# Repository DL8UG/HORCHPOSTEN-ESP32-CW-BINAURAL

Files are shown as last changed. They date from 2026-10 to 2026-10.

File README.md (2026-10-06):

# Horchposten – ESP32 CW Binaural

Binaural CW headphone processor for the ESP32-Audio-Kit (ESP32-A1S).
The audio of a CW transceiver goes into the LINE IN jack; Horchposten
spreads the signals over the stereo image of your headphones, so stations
at different pitches appear at different places and the wanted signal
stands out of the noise.

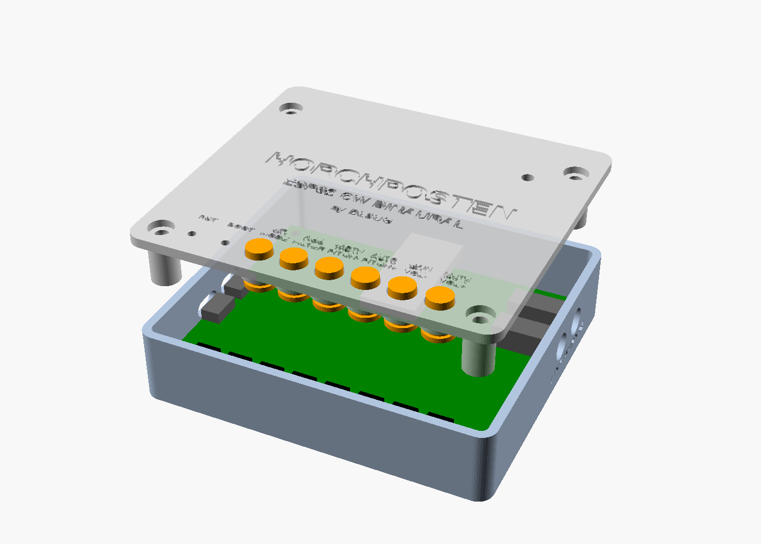
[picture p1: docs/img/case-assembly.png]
Enclosure


> **Status:** work in progress. Signal chain tested on the PC
> (host tests), firmware builds; not yet tested on the hardware.

## Contents

- [Features](#features)
- [Hardware](#hardware)
- [Wiring](#wiring)
- [Keys](#keys)
- [Modes](#modes)
  - [Binaural by pitch](#binaural-by-pitch)
  - [Binaural 90 degrees](#binaural-90-degrees)
  - [Haas](#haas)
  - [Mono](#mono)
- [Filter, AGC and auto pitch](#filter-agc-and-auto-pitch)
- [Flashing](#flashing)
- [Building from source](#building-from-source)
- [Enclosure](#enclosure)
- [Feedback](#feedback)
- [License](#license)
- [Credits](#credits)

## Features

- Four listening modes: binaural by pitch, binaural 90°, Haas, mono
- CW band pass around the centre pitch: off / 500 / 250 / 100 Hz
  (Butterworth, 8th order)
- AGC for strong and weak signals, soft limiter protects the ears
- Auto pitch: one key press sets the centre pitch to the strongest tone
- All settings on six keys, kept over power off
- Codec detection: ES8388 (Audio Kit V2.2) and AC101 boards
- 3D printable enclosure (OpenSCAD, parametric)

## Hardware

- ESP32-Audio-Kit with the ESP32-A1S module (AI-Thinker), V2.2 with
  ES8388 codec; the older AC101 variant is supported but untested
- Headphones (stereo, of course)
- Cable from the transceiver's headphone or line output to the LINE IN jack
- Power over the micro USB socket "POWER" (or "UART", which is also used
  for flashing)

The speaker outputs of the board stay off.

ESP32-Audio-Kit V2.2 from above: keys RST, BOOT, KEY1 to KEY6 along the front edge, EARPHONES and LINE IN on the right, micro USB on the left, DIP switch in the middle, the two microphones marked for removal

**Remove the on-board microphones.** They share the codec input with the
LINE IN jack, and a plug in the jack does not cut them off: on a V2.2
board marked A618, tapping a microphone reached −8 dBFS, louder than a
line signal from a PC, and speech in the room came through. Desolder
both, or cut one leg of each (the one not on the ground plane); then a
tap stays below −45 dBFS. Don't bridge their legs instead: that may
short the line input to ground as well.

## Wiring

Input and output are ordinary 3.5 mm jacks. That keeps Horchposten
universal: it can be put into any headphone connection, between the
transceiver and the headphones (a 6.3 mm socket or plug needs only the
usual adapter).

```
Transceiver            ESP32-Audio-Kit
phones / line out ---> LINE IN  (3.5 mm, tip = left channel is used)
                       PHONES   ---> headphones
                       USB      ---> 5 V
```

- A mono plug works: only the tip (left channel) is used.
- Start with the transceiver's volume low and raise it until the AGC
  holds the level; with AGC off, raise the input gain (KEY5 long) instead.
- If the transceiver has a fixed line output (ACC, data port), use it:
  then the transceiver's volume knob doesn't matter.

## Keys

| Key | Short press | Long press (0.6 s) |
|---|---|---|
| KEY1 | mode: pitch → 90° → Haas → mono | swap left / right |
| KEY2 | filter: off → 500 → 250 → 100 Hz | AGC on / off |
| KEY3 | centre pitch −25 Hz | stereo width: narrow → medium → wide |
| KEY4 | centre pitch +25 Hz | auto pitch |
| KEY5 | volume − | input gain: 0 → 6 → … → 24 dB |
| KEY6 | volume + | mute on / off |

The green LED confirms with short blinks (e.g. the number of the new mode);
one long blink means "not possible" (end of a range, auto pitch found no
clear tone). Every change is also printed in the serial log. Settings are
saved 3 s after the last change; the audio fades out for about 50
milliseconds while the flash is written. Mute is not kept, Horchposten
always starts unmuted.

Centre pitch range: 300–1000 Hz, default 600 Hz. Tip: set it to the CW
pitch of your transceiver, then your own sidetone and a station zero-beat
by the transceiver are in the middle.

KEY2 shares GPIO13 with the SD card and JTAG. If it doesn't react, check
the DIP switch next to the SD slot.

## Modes

How every stage works, with the formulas and numbers behind it, is
explained in [docs/algorithms.md](docs/algorithms.md).

### Binaural by pitch

The main mode. A signal exactly on the centre pitch is in the middle of
your head; lower tones move to the left, higher ones to the right. Several
stations in the passband are spread over the stereo image instead of
lying on top of each other.

How: the signal is split into I and Q (90° apart, Hilbert transformer);
one ear gets the signal, the other the same signal delayed by D and
turned back by the phase of the centre pitch. The phase between the ears
is then 2π (f − f<sub>centre</sub>) D: zero on the centre pitch, growing
with the distance from it. This follows the idea of Rick Campbell's (KK7B)
binaural I/Q receivers, but keeps the pitch of each tone.
The width (KEY3 long) sets D: 90° between the ears is reached 500 Hz
(narrow), 310 Hz (medium) or 200 Hz (wide) away from the centre pitch.

### Binaural 90 degrees

Left and right ear are 90° apart at every frequency. Noise sounds wide and
diffuse, a CW signal stays focussed and seems to stand in front of the
noise.

### Haas

One ear gets the signal some milliseconds later (8 / 15 / 25 ms, by
width). A broad, spacious sound.

### Mono

Both ears the same, for comparison.

## Filter, AGC and auto pitch

- **Filter** (KEY2): band pass centred on the centre pitch. It follows
  every change of the pitch.
- **AGC** (KEY2 long): 3 ms look-ahead, so the first element after a
  pause is no louder than the rest; 150 ms hang, slow decay. Keeps the
  level between weak and strong signals over up to about 35 dB.
- **Auto pitch** (KEY4 long): listens for 0.3 s and sets the centre pitch
  to the strongest tone between 300 and 1000 Hz, if it stands at least
  14 dB above the noise 20–60 Hz beside it. This also works behind a
  narrow CW filter in the transceiver.

## Flashing

Each [release](https://github.com/DL8UG/HORCHPOSTEN-ESP32-CW-BINAURAL/releases) has `horchposten-vX.Y.Z-merged.bin`, one
image for address 0x0:

```sh
pip install esptool
esptool.py --chip esp32 --port /dev/ttyUSB0 write_flash 0x0 horchposten-vX.Y.Z-merged.bin
```

Use the micro USB socket "UART". If the board doesn't enter the download
mode by itself, hold BOOT and press RST. The browser tool
[ESP Tool](https://espressif.github.io/esptool-js/) works too.

## Building from source

ESP-IDF v5.5:

```sh
cd firmware
idf.py set-target esp32
idf.py build flash monitor
```

`idf.py menuconfig` → "Horchposten": codec (auto / fixed), input channel,
LED polarity.

The signal chain (`firmware/main/dsp.c`, `pitch.c`) is plain C and is
tested on the PC:

```sh
make -C firmware/test/host       # checks
make -C firmware/test/host wav   # plus WAV files to listen to (build/wav/, emptied first)
```

The WAV files (16 kHz stereo, listen with headphones) show each part of
the signal chain. The input files are brought to the level of the
processed ones, so loudness doesn't decide the comparison:

| Files | What to listen for |
|---|---|
| `01`–`05` pile-up | three CW stations (480, 600, 760 Hz) in noise: the input, then mono, pitch, 90° and Haas |
| `06`–`07` width | pitch mode narrow / wide on the same pile-up (medium is the default: `03`) |
| `08`–`10` filter | pitch mode with 500 / 250 / 100 Hz |
| `11` sweep | one tone gliding from 300 to 1000 Hz: travels from left to right, in the middle at 600 Hz |
| `12`–`14` AGC | weak station, a very strong one, weak again: the input, AGC on, AGC off |
| `15` changes | a setting changed every 1.5 s on the pile-up (list in `15_changes.txt`); the checks run the same changes on a clean tone and fail on any click |

## Enclosure

A parametric 3D printable enclosure is in [case/](case/README.md). It is
a **draft**: not printed or tested yet, but a solid base for your own
design. Measure your board before printing; the README there says what to
measure.

## Feedback

Please open a [GitHub issue](https://github.com/DL8UG/HORCHPOSTEN-ESP32-CW-BINAURAL/issues) – with the firmware version and
codec from the serial log, your transceiver, and what you did.

## License

Beerware, see [LICENSE](LICENSE).

## Credits

- Binaural I/Q reception: Rick Campbell, KK7B
- Hilbert transformer (allpass pair): Olli Niemitalo
- Board and codec details: the arduino-audiokit project by Phil Schatzmann
  and the Linux AC101 driver (respeaker/seeed-voicecard)

Developed with the help of Claude Code.

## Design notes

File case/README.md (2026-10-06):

# Enclosure

Parametric enclosure for the ESP32-Audio-Kit V2.2 in OpenSCAD:
[horchposten_case.scad](horchposten_case.scad).

Enclosure, exploded view

> **Draft:** this enclosure has not been printed or tested yet. Take it as
> a solid base for your own design.
>
> The layout (one row of eight keys in front, jacks on the right, USB on
> the left, the module antenna out over the back edge) is checked on a
> V2.2 board marked A618. The millimetres come from a product photo with
> dimensions and are **estimates**: measure your board and correct the
> values before the first print (see [Measuring](#measuring)).

## Contents

- [Parts](#parts)
- [Measuring](#measuring)
- [Building the STL files](#building-the-stl-files)
- [Printing](#printing)
- [Assembly](#assembly)
- [Display window](#display-window)

## Parts

| Part | Count | Notes |
|---|---|---|
| `bottom` | 1 | shell with standoffs, openings for the jacks and USB, vent slots |
| `lid` | 1 | key guides, lettering, holes for RESET/BOOT and the LED |
| `buttons` | 1 set | six key plungers |
| M3 x 16 button head screws (ISO 7380) | 4 | through lid and PCB into the standoffs; cap screws (DIN 912) are too tall for the counterbore |
| M3 heat-set inserts | 4 | 4.0 mm hole; for self-tapping screws set `insert_d = 2.6` |
| rubber feet | 4 | 10 mm, self-adhesive |
| clear filament, 3 mm long | 1 | light pipe for the status LED (optional) |

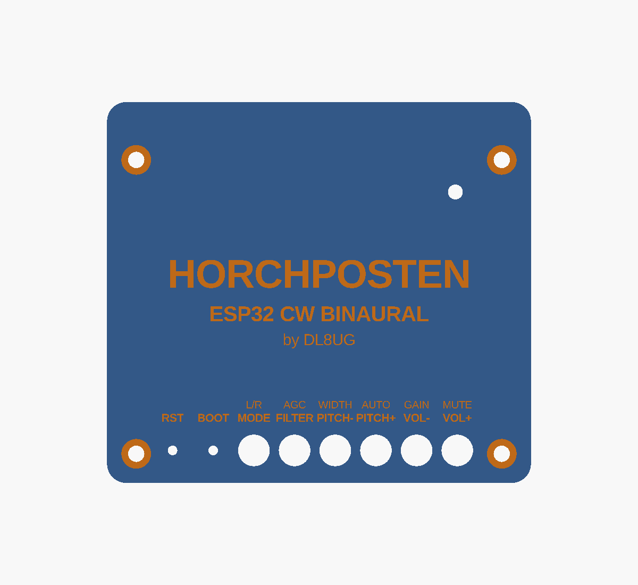
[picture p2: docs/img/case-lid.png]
Lid


## Measuring

All values are in the block "board (MEASURE)" at the top of the SCAD file.
Coordinates are in mm, seen from the top of the board, origin at the front
left corner of the PCB, front edge = the side with the row of keys (from
the left: RST, BOOT, KEY1..KEY6).

| Parameter | What to measure |
|---|---|
| `pcb`, `pcb_t` | PCB size and thickness |
| `holes`, `hole_d` | centres of the four mounting holes |
| `under_h` | tallest part on the underside (solder pins) + 1 mm |
| `over_h` | tallest part on the top + 1 mm |
| `antenna` | x range of the module end that sticks out over the back edge, and how far it sticks out |
| `key_row`, `key_pitch`, `key_top` | centre of RST; distance from key to key; height of the key actuator above the PCB. KEY1..KEY6 and the holes for RST and BOOT follow from these |
| `led` | centre of the status LED (GPIO22) |
| `ports` | for both 3.5 mm jacks (right side) and both micro USB sockets (left side): side, position along that side, centre height above the PCB, opening size |

Check after editing: `part = "assembly"` shows the board dummy in the
shell; jacks and USB plugs must line up with the openings.

## Building the STL files

Ready STL files are in [stl/](stl/), rendered from the SCAD file with the
estimated board positions. After changing parameters, render them again:

```sh
for p in bottom lid buttons; do
  openscad -o stl/$p.stl -D "part=\"$p\"" horchposten_case.scad
done
```

The release workflow does the same and attaches a zip with the STL files
and the SCAD source to each GitHub release.

## Printing

- PLA or PETG, 0.2 mm layers, 3 walls, 20 % infill, no supports.
- `bottom` stands on its floor, `lid` comes out upside down (top face on
  the bed, the lettering is engraved into it), `buttons` stand on their
  flanges.
- Print `buttons` in a different colour from the lid (they are a separate
  part anyway), so the six keys stand out; e.g. a light grey lid with
  orange keys, as in the pictures.
- Contrasting lettering: rub acrylic paint into the engraving and wipe
  the surface clean.

## Assembly

1. Press the heat-set inserts into the standoffs.
2. Put the board in, jacks first through the side openings.
3. Stand the plungers on the keys, flange down, and lower the lid over
   them so that each slides into its guide. (Dropped into the lid from
   below, they fall out when it is turned over; if they won't stand,
   hold them in the lid with a strip of tape across its top face and
   pull it off at the end.) Fasten the lid with the four screws. Don't
   overtighten: the lid tubes clamp the PCB. They are `tube_press`
   (0.2 mm) longer than the room above the board; if a gap stays at the
   rim, lower that value.
4. Rubber feet into the recesses under the bottom.

## Display window

For the later display stage set `display_window = true` and give the
position and size of the window (`display_pos`, `display_size`). If the
display needs more height, raise `over_h`.

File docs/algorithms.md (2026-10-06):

# How Horchposten works

This document explains the signal chain and the auto pitch in detail: what
each stage does, why it is built that way, and the numbers it uses. The
code is in [firmware/main/dsp.c](../firmware/main/dsp.c),
[firmware/main/pitch.c](../firmware/main/pitch.c) and
[firmware/main/audio_io.c](../firmware/main/audio_io.c); the host tests in
[firmware/test/host](../firmware/test/host/dsp_test.c) check the claims made
here.

## Contents

- [Overview](#overview)
- [Audio path and clocks](#audio-path-and-clocks)
- [DC block](#dc-block)
- [CW band pass](#cw-band-pass)
- [AGC](#agc)
- [Hilbert pair: I and Q](#hilbert-pair-i-and-q)
- [Stereo modes](#stereo-modes)
  - [Binaural by pitch](#binaural-by-pitch)
  - [Binaural 90 degrees](#binaural-90-degrees)
  - [Haas](#haas)
  - [Mono and swap](#mono-and-swap)
- [Soft limiter](#soft-limiter)
- [Changes without clicks](#changes-without-clicks)
  - [Handing over new settings](#handing-over-new-settings)
  - [Mode, width and swap](#mode-width-and-swap)
  - [Centre pitch](#centre-pitch)
  - [Band pass](#band-pass)
  - [AGC on and off](#agc-on-and-off)
  - [Output fader and volume](#output-fader-and-volume)
- [Auto pitch](#auto-pitch)
- [How it is tested](#how-it-is-tested)

## Overview

```
LINE IN ─► ADC ─► DC block ─► band pass ─► AGC ─► Hilbert pair ─┬─ I ─► stereo stage ─► limiter ─► fader ─► DAC ─► headphones
 (left)    16 kHz  20 Hz      off/500/     35 dB   90° apart    └─ Q ─►  (mode, width,
                              250/100 Hz                                  swap)
```

Everything runs on one mono input (the left channel of LINE IN) at
16 kHz, in blocks of 64 samples (4 ms). The stereo stage is the only part
that makes two channels. Every change of a setting is faded, so nothing
clicks.

## Audio path and clocks

The ESP32 is I2S master: it sends the bit clock (BCK, 32 × fs), the word
clock (WS, fs) and the codec's master clock (MCLK, 256 × fs) on GPIO0.
The codec (ES8388 on the Audio Kit V2.2) is slave, 16 bit Philips format.

MCLK comes from the ESP32's default PLL, **not from the APLL**. With MCLK
from the APLL, the ES8388 DAC hissed loudly whenever it got any non-zero
data, louder than a tone at −20 dBFS; with the default PLL the output is
clean (found on the board, see the commit history).

The audio task runs on core 1 at high priority: read a block from the
ADC, process it, write it to the DAC. Four DMA buffers of one block each
give 16 ms of buffering.

## DC block

A one-pole high pass removes any DC offset of the ADC before the filters:

```
y[n] = x[n] − x[n−1] + 0.992 · y[n−1]
```

The corner is at (1 − 0.992) · fs / 2π ≈ 20 Hz, far below any CW pitch.

## CW band pass

Four settings: off, 500, 250 and 100 Hz wide, centred on the centre
pitch (300…1000 Hz).

**Design.** A Butterworth band pass of order 8, built from 4 second order
sections (biquads), designed in the firmware when a setting changes:

1. Low pass prototype of order 4: poles on the left half of the unit
   circle, `p_k = e^{jπ(2k + 5)/8}`.
2. Low pass to band pass transform with the band edges pre-warped for the
   bilinear transform: `ω_l = 2fs·tan(π f_l / fs)`, `ω_h` likewise,
   `B = ω_h − ω_l`, `ω0² = ω_l·ω_h`. Each prototype pole gives two band
   pass poles, roots of `s² − p·B·s + ω0² = 0`.
3. Bilinear transform `z = (2fs + s) / (2fs − s)`; only the poles with a
   positive imaginary part are kept, their conjugates are implied.
4. Each section has its zeros at z = 1 and z = −1 (numerator 1 − z⁻²) and
   is scaled to 0 dB at the centre.

The result is −3 dB at fc ± bw/2 and strongly damped at fc ± 2·bw (the
tests ask for more than 20 dB). The sections run in transposed direct
form II, in single precision.

**Why order 8.** A CW filter must be steep enough to cut a neighbour
100 Hz away, but every extra order adds ringing. Order 8 is a usual
compromise for 100…500 Hz CW filters.

How a new filter or a new centre pitch is faded in is described under
[Band pass](#band-pass) further down.

## AGC

The AGC keeps strong and weak signals at about the same level (target
peak 0.3, at most 60 × ≈ 35 dB of gain).

- **Envelope:** peak follower on the filtered signal. A new peak is taken
  at once; the envelope then holds for 150 ms (hang, to bridge the gaps
  between dots and dashes) and decays with a time constant of 300 ms.
- **Gain:** `wanted = 0.3 / max(envelope, 0.3/60)`. The gain follows it
  with a time constant of 0.4 ms when it must go down and 3 ms when it
  goes up (no click when it rises).
- **Look-ahead:** the level is measured on the input, but the gain is
  applied 3 ms later (a 48 sample delay line). So when a station starts
  after a pause, the gain is already down when its first element comes
  out: the first dot is not louder than the rest. The delay is there with
  the AGC off too, so switching it does not shift the signal.

## Hilbert pair: I and Q

The stereo modes need the signal twice, 90° apart over the whole band.
Horchposten uses Olli Niemitalo's allpass design: two chains of four
second order allpass sections,

```
y[n] = a² · (x[n] + y[n−2]) − x[n−2]
```

with the coefficients `a` of the two chains chosen so that their phase
difference stays at 90° ± 0.7° over nearly the whole band. Chain A is
delayed by one more sample. Its output is **I**, the output of chain B is
**Q**; Q leads I by 90°. Both chains have a gain of exactly 1, so the
level is not changed.

Together they form the analytic signal `A = I − jQ`: for a tone
`cos(ωt)` it is `e^{jωt}`, a pointer turning with the tone. Delaying the
signal by D samples turns this pointer back by ωD; multiplying it by
`e^{jθ}` turns it forward by θ. The output of each ear is the real part
of such a pointer. I and Q go into a history of 512 samples, so the
stereo stage can take them with any delay up to 32 ms.

## Stereo modes

### Binaural by pitch

The main mode. One ear gets the signal as it is, the other a version that
is delayed by D and turned by the angle θ = ωc·D, ωc being the centre
pitch:

```
right = I(t)
left  = Re{ A(t − D) · e^{jωc·D} } = I(t − D)·cos(ωc D) + Q(t − D)·sin(ωc D)
```

For a tone at frequency f the left ear lags the right one by

```
Δφ = 2π · (f − fc) · D
```

- at the centre pitch Δφ = 0: the tone is in the middle of the head;
- a higher tone lags in the left ear, so the right ear hears it first:
  it moves to the right;
- a lower tone leads in the left ear: it moves to the left.

The brain locates low tones by the phase difference between the ears, so
each station in the pass band gets its own place between left and right,
by its pitch. That is what makes a pile-up readable: the stations no
longer sit on top of each other.

The width sets D, and so how far from the centre pitch a tone reaches
90° (a clear left or right):

| Width | D | 90° at |
|---|---|---|
| narrow | 8 samples, 0.5 ms | ±500 Hz from the centre |
| medium | 13 samples, 0.81 ms | ±310 Hz |
| wide | 20 samples, 1.25 ms | ±200 Hz |

The level is the same in both ears for every pitch, because I and Q have
the same amplitude.

### Binaural 90 degrees

```
left = I(t),  right = Q(t)
```

Every tone has 90° between the ears, whatever its pitch. This gives a
wide, diffuse image ("in the room" instead of "in the head"); the
stations are not spread by pitch.

### Haas

```
left = I(t),  right = I(t − T)
```

with T = 8, 15 or 25 ms (narrow, medium, wide). The earlier ear wins (the
precedence or Haas effect): the signal seems to come from the left, but
the delayed copy makes it broader and easier to listen to for a long
time.

### Mono and swap

Mono puts I(t) on both ears, as a plain receiver would. Swap exchanges
left and right in every mode.

## Soft limiter

Last stage before the output, against a very hot input or an overshoot:

```
|v| ≤ 0.7 :  v
|v| > 0.7 :  0.7 + 0.3 · o / (1 + o),  o = (|v| − 0.7) / 0.3
```

Linear up to 0.7, then a smooth curve that approaches 1.0 but never
reaches it. Values beyond ±4 are clamped first. With the AGC on, the
limiter only works on short peaks.

## Changes without clicks

A setting that changes from one sample to the next is a step in the
waveform, and a step is a click. Every change in Horchposten is therefore
spread over 20 ms. While a fade runs, a further change waits until it is
over, so a fade is never cut off.

### Handing over new settings

The user interface runs on the other core. It hands new settings over
with a sequence lock: it counts a sequence number up before and after
writing them (odd = being written). At the start of a block the audio task
takes them if the number is even, has changed and did not change while
copying, and if no fade is running. All fades of one change share one
counter.

### Mode, width and swap

The stereo stage runs twice during the fade: once with the old settings,
once with the new ones. A plain mix of the two outputs fails here: for
some pitches the old and the new output are in antiphase (for example
Haas swap at 633 Hz), and a mix of two opposite signals cancels; the
level dropped to 2…5 % for some milliseconds.

So each ear is computed as an analytic signal (a pointer, see above), and
the fade glides from the old pointer zo to the new one zn:

```
level  = |zo| + g · (|zn| − |zo|)
phase  = arg(zo) + g · φ,   φ = arg(zn · conj(zo))
output = level · cos(phase),   g = 0 → 1 over 20 ms
```

φ, the angle between the two pointers, is followed from sample to sample
(unwrapped), so it never jumps by 2π while the level is up. For a single
tone the result keeps its full level and glides in phase; its pitch moves
by at most 25 Hz for these 20 ms, which is not heard as a click.

### Centre pitch

A new centre pitch only changes the angle θ = ωc·D. It is not faded as
above but turned: θ moves in equal steps from the old to the new value
over the 20 ms. The rotation pointer is multiplied by a fixed small turn
per sample (no sine or cosine per sample); the last sample gets the exact
target.

### Band pass

Two cases:

- **A small step of the same filter** (the pitch moves by at most half
  the bandwidth, e.g. 25 Hz with the 100 Hz filter): the poles of the
  running filter glide to the new centre. Each pole is turned and moved
  in equal steps per sample, and the gain follows. The filter keeps its
  state, so a tone in the pass band goes on without a dip. A second
  filter faded in instead would differ in phase at the tone and dip the
  level.
- **Another filter, or a bigger jump**: a glide would sweep over all the
  tones in between. The new filter starts from rest in a second slot and
  is cross-faded with the old one over 20 ms.

The cross-fade of two different filters can still dip a tone for a few
milliseconds where their phases differ much (measured on the host: up to
−10 dB from 500 Hz to off for a tone 200 Hz from the centre). This is an
open point.

### AGC on and off

The AGC's envelope and gain run all the time, also with the AGC off.
Switching only fades a mix factor between 1 and the AGC gain over 20 ms.

### Output fader and volume

After the signal chain, the audio task multiplies the output with a
fader level that ramps in 10 ms. It goes to 0 for mute and for a short
"duck" around hard steps elsewhere:

- a change of the input gain (6 dB per press, a hard step in the codec's
  input amplifier);
- writing the settings to flash, which stalls both cores for some
  milliseconds (about 50 ms of silence in all).

The volume is set in the ES8388's digital DAC volume, which has its own
soft ramp (0.5 dB per 32 samples); the output stage stays fixed at
+4.5 dB. A volume step therefore does not click.

## Auto pitch

A long press on KEY4 records 300 ms of the raw input and looks for the
strongest tone between 300 and 1000 Hz. If it finds one, the centre pitch
is set to it, so that station sits in the middle and the filter is
centred on it.

1. **Window:** the 4800 samples get a Hann window, to keep the side lobes
   of a strong tone away from the bins around it.
2. **Filter bank:** the power at every 5 Hz from 240 to 1060 Hz is
   computed with the Goertzel algorithm (one second order recursion per
   frequency, 165 frequencies). The bank reaches 60 Hz beyond the range
   on purpose (see step 5).
3. **Peak:** the strongest bin.
4. **Is it a tone?** The noise reference is the mean power 20…60 Hz
   beside the peak, without the strongest bin there (another station),
   taken on the side with more noise. The peak must be at least 14 dB
   (25 × in power) above it. A reference from the whole band would fail
   behind a narrow CW filter in the transceiver: most of the band is then
   stop band, and every noise peak in the pass band would count as a
   tone.
5. **Out of range:** if the peak lies outside 300…1000 Hz (more than half
   a bin), the strongest tone is not in the range and there is no result.
   Without the extra bins, a tone at 1015 Hz was taken as 1000 Hz, and
   behind a narrow filter at the edge of the range noise passed as a
   tone in 15…19 % of the captures.
6. **Fine frequency:** a parabola through the logarithmic power of the
   peak bin and its two neighbours gives the frequency between the bins.

Measured over 2000 noise captures each, with and without a 100 or 250 Hz
filter and at the ends of the range, noise passes as a tone in at most
0.15 %. A threshold of 15 dB would remove these but miss five times as
many weak tones (0.015 in noise of 0.1), so it stays at 14 dB.

## How it is tested

The host tests (`make -C firmware/test/host`) run the same C code on the
PC:

- each mode: phase and level between the ears for tones across the band;
- the band pass: level at the centre, −3 dB at the edges, damping far off;
- the AGC: 40 dB of input range gives less than 3 dB of output range; the
  first element after a pause is not louder than the rest;
- clicks: every kind of change on a clean tone; the largest step between
  two samples may be at most 15 % above the tone's own. The test is
  checked against a copy of the code with the fades removed: it must fail
  there;
- dropouts: every mode, width and swap change on tones from 310 to
  1000 Hz; neither ear may drop below 90 % of the level;
- auto pitch: tones at and beyond the edges of the range, noise behind
  transceiver filters, 100 runs each.

`make -C firmware/test/host wav` also writes listening examples, and
`make -C firmware/test/host pileup` a 10 minute busy band (3…8 stations
calling CQ) to play into LINE IN.

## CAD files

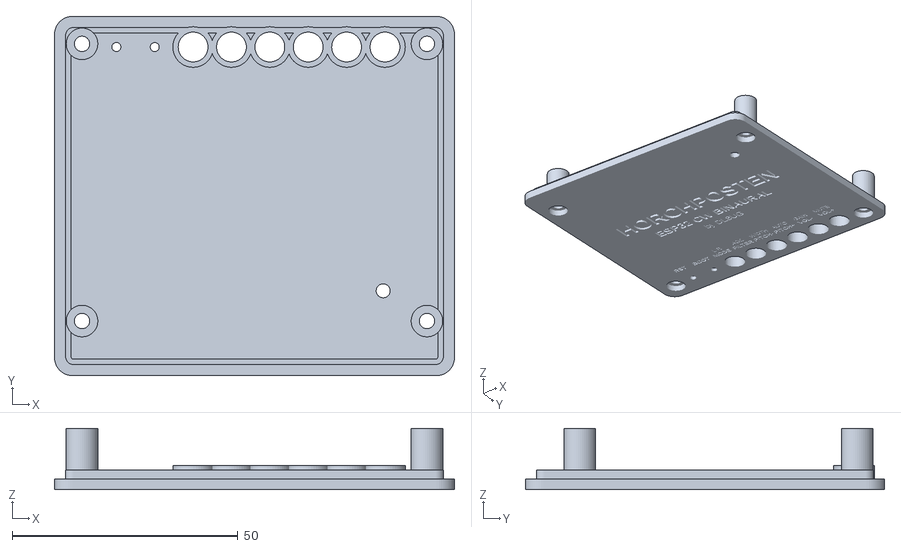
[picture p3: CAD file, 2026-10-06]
case/stl/lid.stl
88.6 x 79.6 x 13.6

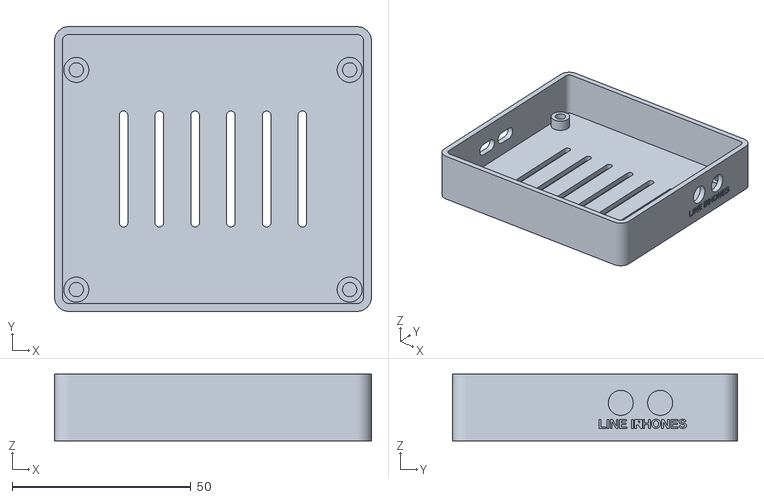
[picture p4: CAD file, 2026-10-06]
case/stl/bottom.stl
88.6 x 79.6 x 18.6

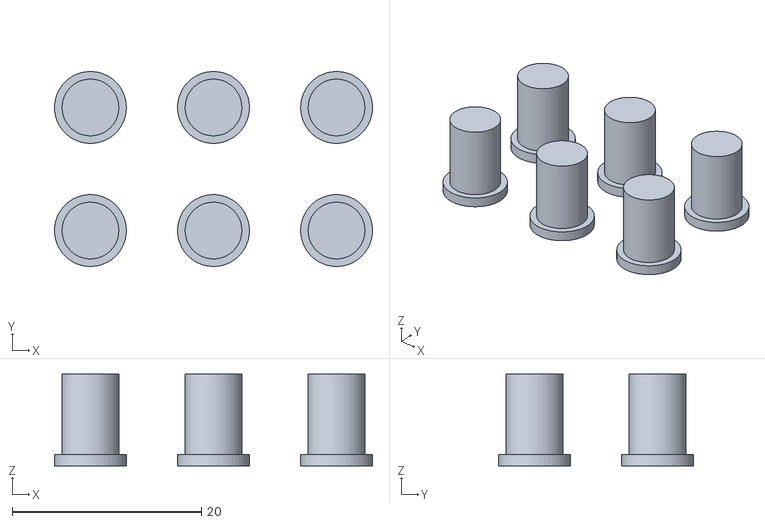
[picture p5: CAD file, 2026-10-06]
case/stl/buttons.stl
33.6 x 20.6 x 9.70

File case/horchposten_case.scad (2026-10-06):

// Horchposten - enclosure for the ESP32-Audio-Kit V2.2 (ESP32-A1S)
//
// Parametric: all board positions are in the block below. The start
// values are estimates; measure your board (see README.md, "Measuring")
// and correct them before the first print.
//
// Parts (select with -D part="..." on the command line):
//   bottom   shell with standoffs and wall openings
//   lid      top plate with key guides, labels and screw tubes
//   buttons  six key plungers
//   assembly preview of everything with a board dummy (default)
//
// Coordinates: x/y in mm on the board, origin = front left PCB corner
// seen from the top, front edge = y 0 (keys side).

part = "assembly";

/* ---------- board (MEASURE) ---------- */
// Start values from a product photo with dimensions (83 x 68 mm); the
// layout (keys in front, jacks right, USB left, antenna out at the back)
// is checked on a V2.2 A618 board, the millimetres are not.
pcb = [83, 68];            // PCB size x, y
pcb_t = 1.6;               // PCB thickness
holes = [[3.3, 3.3], [79.7, 3.3], [3.3, 64.7], [79.7, 64.7]];  // mounting holes
hole_d = 3.2;              // mounting hole diameter
under_h = 4.0;             // room under the PCB (solder pins, battery connector)
over_h = 11.0;             // room above the PCB (tallest part + margin)
// the antenna end of the ESP32-A1S module sticks out over the back edge:
// [x from, x to, how far out]
antenna = [33.5, 48.5, 6.0];

// one row of eight keys along the front edge: RST, BOOT, KEY1..KEY6
key_pitch = 8.5;
key_row = [10.9, 4.0];     // centre of RST; the others follow at key_pitch
key_top = 5.0;             // height of the switch actuator top above the PCB
keys = [for (i = [2:7]) [key_row[0] + i * key_pitch, key_row[1]]];   // KEY1..KEY6
// short / long press function, printed on the lid
key_labels = [["MODE", "L/R"], ["FILTER", "AGC"], ["PITCH-", "WIDTH"],
              ["PITCH+", "AUTO"], ["VOL-", "GAIN"], ["VOL+", "MUTE"]];

// RST and BOOT: holes for a paper clip, no plungers (BOOT stops the codec
// clock while it is held)
pin_holes = [key_row, [key_row[0] + key_pitch, key_row[1]]];
// status LED (GPIO22): hole for a piece of clear filament as light pipe
led = [70, 58];

// wall openings: [label, side, position along the side, centre height above
// the PCB top, width, height, round?]; side: "left" (x 0), "right", "front"
// (y 0), "back"
ports = [
    ["LINE IN", "right", 44.2, 3.0, 7.0, 7.0, true],
    ["PHONES",  "right", 55.2, 3.0, 7.0, 7.0, true],
    ["POWER",   "left",  24.7, 1.8, 9.0, 4.5, false],
    ["UART",    "left",  35.9, 1.8, 9.0, 4.5, false],
];

/* ---------- enclosure ---------- */
clear = 0.6;               // gap PCB to wall
wall = 2.2;
floor_t = 2.0;
lid_t = 2.4;
corner_r = 4;
screw_d = 3.4;             // M3 clearance in the lid
screw_head_d = 6.2;        // counterbore for M3 button head screws (ISO 7380:
screw_head_h = 1.8;        // head 5.7 x 1.65 mm), sunk a little below the top
insert_d = 4.0;            // M3 heat-set insert (or 2.6 for self-tapping screws)
standoff_d = 7;
foot_d = 10.5;             // recesses for self-adhesive rubber feet (10 mm)
foot_h = 0.8;
foot_inset = 14;           // foot centre from the outer edges; clear of the standoffs
key_hole_d = 6.6;          // lid guide for the plungers
plunger_d = 6.0;           // 0.3 mm play on each side in the guide
plunger_flange_d = 7.6;    // < key_pitch: neighbouring flanges must not touch
plunger_flange_h = 1.2;
plunger_above = 1.6;       // how far the plungers stand above the lid
tube_press = 0.2;          // lid tubes this much longer than the room above the PCB
engrave = 0.6;             // depth of the lid lettering
font = "Liberation Sans:style=Bold";

// later stage: window for a display in the lid
display_window = false;
display_pos = [20, 30];    // front left corner of the window on the board
display_size = [42, 32];

/* ---------- derived ---------- */
inner = [pcb[0] + 2 * clear, pcb[1] + 2 * clear + antenna[2]];   // room for the antenna
outer = [inner[0] + 2 * wall, inner[1] + 2 * wall];
pcb_z = floor_t + under_h;                 // PCB bottom
pcb_top = pcb_z + pcb_t;
shell_h = pcb_top + over_h;                // bottom shell height = lid underside
off = [wall + clear, wall + clear];        // PCB origin in shell coordinates
// the back feet move forward with the antenna room, in line with the board
feet = [for (x = [foot_inset, outer[0] - foot_inset],
             y = [foot_inset, outer[1] - foot_inset - antenna[2]]) [x, y]];

// a foot recess under a standoff would leave almost no floor under the insert
assert(plunger_flange_d < key_pitch - 0.5, "plunger flanges touch: lower plunger_flange_d");
for (f = feet, h = holes)
    assert(norm(f - (off + h)) >= (foot_d + standoff_d) / 2 + 0.5,
           str("foot at ", f, " runs into the standoff at ", off + h, ": raise foot_inset"));

$fn = 48;

module rounded_box(size, r, h) {
    linear_extrude(h)
        offset(r) offset(-r) square(size);
}

module at_board(p) { translate([off[0] + p[0], off[1] + p[1], 0]) children(); }

module port_cut(p) {
    side = p[1]; pos = p[2]; zc = pcb_top + p[3]; w = p[4]; h = p[5];
    // cut through the wall, a bit into the inside
    len = wall + clear + 2;
    module shape() {
        if (p[6]) cylinder(d = w, h = len);
        else hull() for (s = [-1, 1]) translate([s * (w - h) / 2, 0, 0]) cylinder(d = h, h = len);
    }
    if (side == "left")
        translate([-1, off[1] + pos, zc]) rotate([0, 90, 0]) rotate([0, 0, 90]) shape();
    else if (side == "right")
        translate([outer[0] + 1, off[1] + pos, zc]) rotate([0, -90, 0]) rotate([0, 0, 90]) shape();
    else if (side == "front")
        translate([off[0] + pos, -1, zc]) rotate([-90, 0, 0]) shape();
    else
        translate([off[0] + pos, outer[1] + 1, zc]) rotate([90, 0, 0]) shape();
}

// label next to a port on the outside of the wall
module port_label(p) {
    side = p[1]; pos = p[2]; zc = pcb_top + p[3];
    // above the opening if there is room below the lid, else below it
    z_up = zc + p[5] / 2 + 1.0;
    z = z_up + 3 < shell_h - 0.5 ? z_up : zc - p[5] / 2 - 3.6;
    if (z > 0.8) {
        if (side == "left")
            translate([engrave - 0.01, off[1] + pos, z]) rotate([90, 0, -90])
                linear_extrude(engrave + 1) text(p[0], size = 2.6, font = font, halign = "center");
        else if (side == "right")
            translate([outer[0] - engrave + 0.01, off[1] + pos, z]) rotate([90, 0, 90])
                linear_extrude(engrave + 1) text(p[0], size = 2.6, font = font, halign = "center");
        else if (side == "front")
            translate([off[0] + pos, engrave - 0.01, z]) rotate([90, 0, 0])
                linear_extrude(engrave + 1) text(p[0], size = 2.6, font = font, halign = "center");
        else
            translate([off[0] + pos, outer[1] - engrave + 0.01, z]) rotate([90, 0, 180])
                linear_extrude(engrave + 1) text(p[0], size = 2.6, font = font, halign = "center");
    }
}

module bottom() {
    difference() {
        union() {
            difference() {
                rounded_box(outer, corner_r, shell_h);
                translate([wall, wall, floor_t]) rounded_box(inner, max(corner_r - wall, 0.5), shell_h);
            }
            // standoffs under the mounting holes
            for (h = holes) at_board(h) cylinder(d = standoff_d, h = pcb_z);
        }
        // screw holes for heat-set inserts, all the way down for M3x16
        for (h = holes) at_board(h) translate([0, 0, 1]) cylinder(d = insert_d, h = pcb_z);
        for (p = ports) port_cut(p);
        for (p = ports) port_label(p);
        // vent slots in the floor, away from the standoffs
        for (i = [0:5]) translate([outer[0] / 2 - 25 + i * 10, outer[1] / 2 - 15, -1])
            hull() for (y = [0, 30]) translate([0, y, 0]) cylinder(d = 2.4, h = floor_t + 2);
        // recesses for self-adhesive rubber feet
        for (f = feet) translate([f[0], f[1], -0.01]) cylinder(d = foot_d, h = foot_h);
    }
}
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

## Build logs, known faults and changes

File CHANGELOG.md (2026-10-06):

# Changelog

All notable changes to this project are documented in this file.
The format follows [Keep a Changelog](https://keepachangelog.com/en/1.1.0/),
versions follow [Semantic Versioning](https://semver.org/).

## [Unreleased]

## [0.1.0] - 2026-10-06

First version. Tested on an ESP32-Audio-Kit V2.2 (A618, ES8388) with
audio from a PC; not yet with a transceiver.

### Added

- Signal chain: DC block, CW band pass (off/500/250/100 Hz, Butterworth
  8th order), AGC with look-ahead, Hilbert pair, stereo modes binaural by
  pitch, binaural 90°, Haas and mono, soft limiter. Every change of mode,
  width, swap, filter, pitch and AGC is faded without clicks; mode, width
  and swap changes glide in phase, so no tone drops out.
- Auto pitch on the strongest tone (300–1000 Hz); no result for a tone
  outside the range.
- Firmware for the ESP32-Audio-Kit: codec detection ES8388 / AC101, six
  keys with short and long press, status LED confirms every change,
  settings kept in flash (written only when they changed). Volume (soft
  ramp), input gain and mute are faded, and so is the output while the
  settings are written to flash.
- Host tests of the signal chain with WAV output; a generator for a busy
  CW band (`tools/pileup.c`) to play into LINE IN.
- Documentation: how the signal chain works (`docs/algorithms.md`), a
  drawing of the board.
- Parametric 3D printable enclosure (OpenSCAD), a draft.
- CI: host tests, firmware build, documentation check; release workflow.

### Known issues

- The two on-board microphones share the line input: remove them (see
  the README, Hardware).
- Changing the band pass filter, or an auto pitch jump with a filter on,
  can dip a tone for a few milliseconds.
- AC101 boards are untested; their volume steps are hard (no ramp).
- Enclosure: dimensions from a product photo, not measured; not printed
  or tested yet.

[Unreleased]: https://github.com/DL8UG/HORCHPOSTEN-ESP32-CW-BINAURAL/compare/v0.1.0...HEAD
[0.1.0]: https://github.com/DL8UG/HORCHPOSTEN-ESP32-CW-BINAURAL/releases/tag/v0.1.0

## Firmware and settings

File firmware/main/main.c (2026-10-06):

/*
 * Horchposten - binaural CW headphone processor for the ESP32-Audio-Kit.
 *
 * LINE IN (transceiver audio) -> signal chain (dsp.c) -> headphones.
 * Keys (short / long press):
 *   KEY1 mode            / swap left-right
 *   KEY2 filter width    / AGC on-off
 *   KEY3 pitch -25 Hz    / stereo width
 *   KEY4 pitch +25 Hz    / auto pitch
 *   KEY5 volume -        / input gain
 *   KEY6 volume +        / mute
 */
#include <stdio.h>

#include "audio_io.h"
#include "board.h"
#include "buttons.h"
#include "codec.h"
#include "dsp.h"
#include "esp_app_desc.h"
#include "esp_log.h"
#include "freertos/FreeRTOS.h"
#include "freertos/task.h"
#include "led.h"
#include "pitch.h"
#include "settings.h"
#include "ui_state.h"

#define PITCH_STEP_HZ   25
#define UI_TICK_MS      100
#define MAX_LISTENERS   4

static const char *TAG = "horch";

static ui_state_t s_st;
static ui_listener_t s_listeners[MAX_LISTENERS];

void ui_add_listener(ui_listener_t cb)
{
    for (int i = 0; i < MAX_LISTENERS; i++) {
        if (!s_listeners[i]) {
            s_listeners[i] = cb;
            return;
        }
    }
}

static void notify(ui_event_t ev)
{
    for (int i = 0; i < MAX_LISTENERS; i++)
        if (s_listeners[i])
            s_listeners[i](ev, &s_st);
}

static void log_listener(ui_event_t ev, const ui_state_t *st)
{
    static const char *widths[] = { "narrow", "medium", "wide" };
    const char *what = ev == UI_EV_AUTO_OK ? "auto pitch: " : ev == UI_EV_AUTO_FAIL
                       ? "auto pitch: no clear tone, " : "";
    int bw = dsp_filter_bw_hz(st->dsp.filter);
    char filt[8];
    if (bw)
        snprintf(filt, sizeof(filt), "%d", bw);
    else
        snprintf(filt, sizeof(filt), "off");
    ESP_LOGI(TAG, "%smode %s, filter %s, pitch %d Hz, width %s, agc %s, swap %s, "
             "vol %d, gain %d dB%s", what, dsp_mode_name(st->dsp.mode), filt,
             st->dsp.pitch_hz, widths[st->dsp.width], st->dsp.agc ? "on" : "off",
             st->dsp.swap ? "on" : "off", st->volume, st->in_gain_db,
             st->mute ? ", MUTED" : "");
}

static void apply_input_gain(void)
{
    if (codec_set_input_gain(s_st.in_gain_db) == ESP_OK)
        audio_set_digital_gain(0);
    else
        audio_set_digital_gain(s_st.in_gain_db);
}

/* the input gain jumps up to 24 dB: hide the step under the fader, and
 * wait until the samples in the DMA buffers have the new gain */
static void change_input_gain(void)
{
    audio_duck(true);
    audio_wait_fader();
    apply_input_gain();
    vTaskDelay(pdMS_TO_TICKS(30));
    audio_duck(false);
}

/* fade first, then the codec mute (a hard step on the AC101) */
static void set_mute(bool mute)
{
    if (mute) {
        audio_set_mute(true);
        audio_wait_fader();
        codec_set_mute(true);
    } else {
        codec_set_mute(false);
        audio_set_mute(false);
    }
}

/* before audio_start: nothing plays yet, the fader starts at 0 */
static void apply_all(void)
{
    dsp_set_params(&s_st.dsp);
    apply_input_gain();
    codec_set_volume(s_st.volume);
    audio_set_mute(s_st.mute);
    codec_set_mute(s_st.mute);      /* last: the codecs start muted */
}

/* the flash write stalls the audio task (cache off): fade out around it */
static void save_settings(void)
{
    if (!settings_due())
        return;
    audio_duck(true);
    audio_wait_fader();
    settings_save();
    audio_duck(false);
}

static void auto_pitch(void)
{
    static float buf[DSP_FS * PITCH_CAPTURE_MS / 1000];
    const size_t n = sizeof(buf) / sizeof(buf[0]);
    float hz;
    if (audio_capture(buf, n, 2 * PITCH_CAPTURE_MS)
        && pitch_detect(buf, n, DSP_FS, DSP_PITCH_MIN, DSP_PITCH_MAX, &hz)) {
        s_st.dsp.pitch_hz = (int)(hz + 0.5f);
        dsp_set_params(&s_st.dsp);
        led_blink(1);
        notify(UI_EV_AUTO_OK);
        settings_changed(&s_st);
    } else {
        led_error();
        notify(UI_EV_AUTO_FAIL);
    }
}

/* returns false if nothing changed (a limit was hit) */
static bool handle(const button_event_t *ev)
{
    dsp_params_t *d = &s_st.dsp;
    bool dsp = true;        /* a signal chain setting changed */
    bool save = true;
    switch (ev->key * 2 + ev->long_press) {
    case 0:     /* KEY1 short: mode */
        d->mode = (d->mode + 1) % DSP_MODE_COUNT;
        led_blink(d->mode + 1);
        break;
    case 1:     /* KEY1 long: swap */
        d->swap = !d->swap;
        led_blink(d->swap ? 2 : 1);
        break;
    case 2:     /* KEY2 short: filter */
        d->filter = (d->filter + 1) % DSP_FILTER_COUNT;
        led_blink(d->filter + 1);
        break;
    case 3:     /* KEY2 long: AGC */
        d->agc = !d->agc;
        led_blink(d->agc ? 2 : 1);
        break;
    case 4:     /* KEY3 short: pitch down */
    case 6:     /* KEY4 short: pitch up */
    {
        /* clamped by the signal chain's own rule, so the limits can be
         * reached from an auto pitch value off the 25 Hz grid */
        dsp_params_t n = *d;
        n.pitch_hz += ev->key == 2 ? -PITCH_STEP_HZ : PITCH_STEP_HZ;
        dsp_params_sanitize(&n);
        if (n.pitch_hz == d->pitch_hz)
            return false;
        d->pitch_hz = n.pitch_hz;
        led_blink(1);
        break;
    }
    case 5:     /* KEY3 long: width */
        d->width = (d->width + 1) % DSP_WIDTH_COUNT;
        led_blink(d->width + 1);
        break;
    case 7:     /* KEY4 long: auto pitch */
        auto_pitch();
        return true;    /* applied and reported there */
    case 8:     /* KEY5 short: volume down */
    case 10:    /* KEY6 short: volume up */
    {
        int v = s_st.volume + (ev->key == 4 ? -1 : 1);
        if (v < 0 || v > CODEC_VOL_MAX)
            return false;
        s_st.volume = v;
        codec_set_volume(v);
        led_blink(1);
        dsp = false;
        break;
    }
    case 9:     /* KEY5 long: input gain */
        s_st.in_gain_db = (s_st.in_gain_db + UI_GAIN_STEP_DB) % (UI_GAIN_MAX_DB + UI_GAIN_STEP_DB);
        change_input_gain();
        led_blink(s_st.in_gain_db / UI_GAIN_STEP_DB + 1);
        dsp = false;
        break;
    case 11:    /* KEY6 long: mute */
        s_st.mute = !s_st.mute;
        set_mute(s_st.mute);
        led_blink(s_st.mute ? 2 : 1);
        dsp = false;
        save = false;       /* mute is not kept over a restart */
        break;
    default:
        return false;
    }
    if (dsp)
        dsp_set_params(d);
    notify(UI_EV_CHANGED);
    if (save)
        settings_changed(&s_st);
    return true;
}

static void fail_forever(const char *why)
{
    ESP_LOGE(TAG, "%s", why);
    for (;;) {
        led_error();
        vTaskDelay(pdMS_TO_TICKS(2000));
    }
}

void app_main(void)
{
    ESP_LOGI(TAG, "Horchposten %s", esp_app_get_description()->version);
    board_init();
    led_init();
    settings_load(&s_st);

    codec_type_t codec = codec_probe();
    if (codec == CODEC_NONE)
        fail_forever("no audio codec found - is this an ESP32-Audio-Kit?");
    audio_io_init(codec == CODEC_ES8388 ? &board_i2s_es8388 : &board_i2s_ac101);
    if (codec_init() != ESP_OK)
        fail_forever("codec init failed");

    dsp_init(&s_st.dsp);
    apply_all();        /* volume and mute before the first sample */
    audio_start();

    ui_add_listener(log_listener);
    notify(UI_EV_CHANGED);
    buttons_init();
    led_blink(s_st.dsp.mode + 1);

    for (;;) {
        button_event_t ev;
        if (buttons_get(&ev, UI_TICK_MS) && !handle(&ev))
            led_error();
        save_settings();
    }
}

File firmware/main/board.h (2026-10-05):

/*
 * Pins of the ESP32-Audio-Kit (ESP32-A1S). Two variants exist: V2.2 with
 * an ES8388 codec and an older one with an AC101; they differ in the I2S
 * word select and data out pins.
 * Source: board definitions of pschatzmann/arduino-audiokit.
 */
#pragma once

#include "driver/gpio.h"

#define BOARD_I2C_SDA       GPIO_NUM_33
#define BOARD_I2C_SCL       GPIO_NUM_32
#define BOARD_I2S_MCLK      GPIO_NUM_0
#define BOARD_I2S_BCK       GPIO_NUM_27
#define BOARD_I2S_DIN       GPIO_NUM_35
#define BOARD_PA_ENABLE     GPIO_NUM_21     /* speaker amplifier, kept off */
#define BOARD_LED           GPIO_NUM_22

#define BOARD_KEY_COUNT     6
/* KEY1..KEY6; KEY2 (GPIO13) depends on the DIP switch setting */
extern const gpio_num_t board_keys[BOARD_KEY_COUNT];

typedef struct {
    gpio_num_t ws;
    gpio_num_t dout;
} board_i2s_pins_t;

extern const board_i2s_pins_t board_i2s_es8388;
extern const board_i2s_pins_t board_i2s_ac101;

/* speaker amplifier off: the output is for headphones only */
void board_init(void);

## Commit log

2026-10-05 Add signal chain, auto pitch and host tests
    Band pass (Butterworth, 8th order), AGC, Hilbert pair, stereo modes
    pitch/iq90/haas/mono with cross-fade; Goertzel auto pitch. Host tests
    check phases, levels, filter edges, AGC range, fades and auto pitch,
    and write WAV files to listen to.
2026-10-05 Add ESP-IDF firmware
    Codec detection (ES8388 / AC101) with own register drivers, I2S full
    duplex at 16 kHz with MCLK from the APLL, audio task, key handling with
    short/long press, status LED, settings in NVS, auto pitch on KEY4 long.
    [board.h, buttons.c, codec.c]
2026-10-05 Add parametric enclosure (OpenSCAD)
    Bottom shell, lid with key guides and lettering, key plungers; board
    positions are estimates until measured on the real board.
    [horchposten_case.scad]
2026-10-05 Add CI, release workflow, issue templates
    Build: host tests + ESP-IDF build. Release on tag v*: firmware (merged
    and single images), enclosure STL zip, draft release with the notes
    from CHANGELOG.md. Docs: link and Contents check. Dependabot for actions.
2026-10-05 Commit rendered enclosure STL files
    [bottom.stl, buttons.stl, lid.stl]
2026-10-05 Add "by DL8UG" to the lid lettering
    [horchposten_case.scad, lid.stl]
2026-10-05 Auto pitch: raise the tone threshold to 14 dB
    At 10 dB above the median, white noise passed as a tone in about 16 %
    of the 0.3 s captures, so auto pitch set a random pitch instead of
    blinking an error. From 13 dB on no capture of 2000 passed; a tone of
    0.05 in noise of 0.1 is still found every time.
2026-10-05 DSP: fade every change, AGC with look-ahead
    AGC: the peak is taken from the input and the gain applied 3 ms later.
    Before, the gain was still high when the first element after a pause
    came out (+10 dB after 2 s of silence, +5 dB after a word gap). The
    detector runs with the AGC off too, and on/off is faded.
    Pitch mode: a new centre pitch moved the rotation of the delayed ear in
    one sample (step 0.46 from 600 to 1000 Hz). It now glides over 20 ms;
    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
2026-10-05 Start the headphones muted, apply the settings before the audio
    The AC101 init switched the headphone amplifier on at volume 60 of 63
    with the DAC not muted, and the audio task started before apply_all()
    set the saved volume: a loud burst at every power-on. The AC101 now
    starts muted at volume 0 like the ES8388, and apply_all() runs before
    audio_start(), unmuting last.
2026-10-05 Settings: never start muted, one range check
    A device muted before power-off started silent with nothing showing
    why. Mute is still stored but cleared on load.
    settings_load() repeated the range checks of the signal chain by hand
    and already differed (bad pitch -> 600 instead of clamped). It now
    calls dsp_params_sanitize(); the input gain must also be a multiple of
    the 6 dB step, else its blink count comes out wrong.
2026-10-05 Enclosure: lid tubes clamp the PCB, plungers without double clearance
    The lid tubes ended 0.2 mm above the PCB, so the board could rattle on
    the screws although the tubes are meant to clamp it. They are now
    tube_press = 0.2 mm longer than the room above the board.
    The plunger shaft was plunger_d - 0.4 = 5.6 mm in the 6.6 mm guide,
    0.5 mm play on each side; plunger_d already holds the clearance.
    STL files and doc images rendered again.
    [buttons.stl, horchposten_case.scad, lid.stl]
2026-10-05 Enclosure: counterbore for M3 button head screws
    The 1.6 mm counterbore was too shallow for the M3 cap screws of the
    parts list (DIN 912 heads are 3 mm tall), they stood about 1.4 mm
    proud. The parts list now names button head screws (ISO 7380, head
    1.65 mm), the counterbore is 1.8 mm deep.
    [horchposten_case.scad, lid.stl]
2026-10-06 Write README and CHANGELOG
    README: features, hardware, wiring, keys, the four modes and how the
    pitch mode works, filter/AGC/auto pitch, flashing, building, host
    tests, enclosure, feedback, credits. CHANGELOG: everything so far
    under [Unreleased].
2026-10-06 Host tests: listening examples for every part of the signal chain
    make wav now writes 16 files to build/wav/: the pile-up in every mode
    (with the input for comparison), the three widths, the three filters,
    a 300-1000 Hz sweep through the stereo image, an AGC scene with weak
    and very strong stations, and a run with a setting change every 1.5 s
    plus its timeline.
2026-10-06 LED: build with an active-high LED too
    A bool option set to n is not defined in sdkconfig.h, so the C
    expression did not compile. Use #if, as audio_io.c does.
2026-10-06 Keys: pitch steps reach the limits, only DSP keys touch the DSP
    A pitch step past 300 or 1000 Hz is clamped instead of rejected, so the
    limits can be reached after auto pitch set a value off the 25 Hz grid.
    Volume, input gain and mute no longer hand unchanged parameters to the
    audio task, and mute no longer triggers a flash write.
    [main.c]
2026-10-06 Audio: fade mute, input gain and the settings save; ES8388 volume ramps
    An output fader in the audio task (10 ms ramps) now carries mute, and
    ducks the output around an input gain change (up to 24 dB at once) and
    around the flash write of the settings, which stalls the audio task.
    The I2S ISR stays in IRAM so the DMA buffers are cleared meanwhile.
    The ES8388 volume moved from the output stage, which jumps, to the DAC
    digital volume with soft ramp (1.5 dB in 6 ms); the range stays
    +4.5 to -40.5 dB. The AC101 volume still steps hard.
    [codec_es8388.c, main.c]
2026-10-06 DSP: the band pass glides along with small pitch steps
    A pitch step with the filter on cross-faded the old band pass into a new
    one at the other centre. At the tone the two differ in phase, so the
    level dipped by 3.3 dB for a 25 Hz step with the 100 Hz filter. Steps up
    to half the bandwidth now turn the poles of the filter in use to the new
    centre while the pitch glides (now at most 0.4 dB); larger jumps are
    still cross-faded, a glide would sweep over the tones in between.
    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
2026-10-06 Auto pitch: compare the peak with the noise beside it
    The threshold was set against the median of the whole 300-1000 Hz band.
    Behind a 100 or 250 Hz CW filter in the transceiver that median lies in
    the stop band, and plain noise passed as a tone in every capture. The
    reference is now the mean power 20-60 Hz beside the peak, without its
    strongest bin, on the noisier side. Over 2000 captures each, with and
    without such a filter, noise passes in at most 0.1 %, and weak tones are
    missed less often than before.
    The host test runs 100 noise and 100 tone captures behind such filters
    and without one.
2026-10-06 Enclosure: rubber feet clear of the standoffs
    The foot recesses sat 10 mm from the corners, right under the heat-set
    insert holes, and left 0.2 mm of floor under them: pressing the inserts
    would push plastic through. The feet move to 14 mm (10.9 mm from each
    insert), and an assert stops the render if a foot runs into a standoff
    again.
    [bottom.stl, horchposten_case.scad]
2026-10-06 Host tests: check the setting changes for clicks, tidy the WAV output
    The 1.5 s change list now also runs as a check on a clean tone with four
    phases (a hard switch can land where both sides happen to match); the
    limit is the tone's own largest step plus 15 %. Without the fades the
    check fails on mode and filter changes. In the pile-up's noise a click
    would have gone unheard.
    WAV output: make wav empties build/wav first, dsp_test takes the
    directory as an argument (--wav DIR) and creates only that one, write
    errors count as failures, the input files are matched to the RMS level
    of the processed ones. Test stations stop at a key-up instead of cutting
    an element, CQ has 3 units between C and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
2026-10-06 Host tests: the click checks can fail now
    test_steps measured from the change on, so the step between the last
    old and the first new sample, where a hard switch lands, was never
    looked at. Its 600 Hz tone at the 600 Hz centre pitch and the AGC
    target level also made swap, width, Haas -> mono, mono -> pitch and
    AGC on/off change nothing at all. The tone is now 430 Hz at 0.1, and
    the check starts one sample before the change. With every fade
    removed, each of these steps fails the test now.
    test_xfade had the same blind spot (pitch -> Haas at the centre pitch
    is the same signal); it uses 650 Hz.
2026-10-06 AC101: 1.5 dB per volume press, as on the ES8388
    The headphone volume register has 1 dB steps (63 = 0 dB, Linux ac101
    driver), so vol * 2 + 3 gave 2 dB per press and -60..0 dB. Steps of
    1 and 2 dB in turn now give 1.5 dB per press and -45..0 dB, the same
    45 dB span as the ES8388.
2026-10-06 Auto pitch: no edge results for tones out of range
    A tone just outside 300..1000 Hz peaked in the edge bin and was taken
    as 300 or 1000 Hz. Behind a narrow transceiver filter at the edge of
    the range, the noise reference beyond the edge was missing and the
    other side lay in the stop band: noise passed as a tone in 15 to 19 %
    of the captures. The filter bank reaches 60 Hz beyond the range now; a
    peak out there gives no result, and an edge peak has its reference on
    both sides. Noise passes in at most 0.15 % now (2000 runs each, edges
    included); a higher threshold would cost weak tones.
    The tests check tones at the edges, tones just outside and filters at
    the edges, and seed their noise, so th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
2026-10-06 DSP: mode, width and swap fades no longer drop out
    A plain mix of the old and the new stereo output cancels where the two
    are in antiphase: Haas swap at 633 Hz, Haas medium -> wide at 450 Hz
    or a swap at wide width with a station 400 Hz off the centre dipped to
    0.02..0.05 of the level for some ms. Each ear now comes out of the
    stereo stage as an analytic signal (I - jQ); during the 20 ms fade its
    level moves linearly and its phase glides from the old output to the
    new one, followed from sample to sample, so it never jumps.
    test_xfade_level runs every mode change, swap and width step on tones
    from 310 to 1000 Hz: neither ear may drop below 0.27 of 0.3, and no
    step may exceed the tone's own b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
2026-10-06 Settings: no flash write when nothing changed
    AGC pressed twice, or pitch up and down again within 3 s, still faded
    the audio out for about 50 ms and wrote the same values to flash.
    settings_changed compares with what the flash holds and drops the
    pending save when they are equal.
2026-10-06 Keys: pitch and volume steps blink the LED
    The README promises a short blink for every change, but pitch and
    volume steps showed nothing, which looks the same as a key that does
    not react. They blink once now. The pitch step is clamped by
    dsp_params_sanitize instead of a copy of its range rule.
    [main.c]
2026-10-06 DSP: one counter for the fades of a change, glides without cosf
    The four fade counters always started together at XFADE_N, and
    pending_seq repeated seq; a change that started one without the other
    could have put them out of step. One counter now runs the fades of the
    last change, flags say which run, and take_pending reads seq alone.
    The pitch and band pass glides called cosf and sinf on every sample
    (six calls for 320 samples per step). They turn a phasor by a fixed
    step per sample now and set the exact target on the last sample. The
    listening examples differ by at most 3 LSB.
2026-10-06 Enclosure: plungers go on the keys before the lid
    Dropped into the lid from below, the plungers (9.7 mm long, 5.4 mm in
    the guide) slide out as soon as the lid is turned over. They stand on
    the keys now and the lid is lowered over them; a strip of tape holds
    them in the lid if they won't stand.
2026-10-06 ES8388: volume in the output stage, the hiss goes down with it
    On the board (Audio Kit V2.2) the headphones hissed loudly at every
    volume: the hiss comes from the codec ahead of its output stage, and
    the stage stood fixed at +4.5 dB while the volume was set in the DAC.
    Mute or no input changed nothing; stopping MCLK silenced it. The
    volume is set in the output stage now (-40.5..+4.5 dB as before), the
    DAC stays at 0 dB, and the hiss follows the volume (heard on the
    board). The output stage has no ramp, so a volume step is a hard
    1.5 dB step.
    [codec_es8388.c]
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2026-10-06 ES8388: volume back in the DAC with its soft ramp
    Reverts c52de32. The volume went into the output stage only to keep
    the hiss down; the hiss came from MCLK out of the APLL and is gone
    since df426de. The DAC volume ramps (no click on a volume step), the
    output stage stays fixed at +4.5 dB.
    [codec_es8388.c]
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2026-10-06 Tools: generator for a busy CW band to play into LINE IN
    tools/pileup.c writes a 48 kHz WAV with 3..8 stations at a time
    calling CQ, CQ TEST, CQ POTA or CQ SOTA, coming and going on pitches
    350..950 Hz (30 Hz apart while both are on), with fading, drift and
    receiver noise, plus a timeline of who calls when on which pitch.
    "make -C firmware/test/host pileup" renders 10 minutes (seed 3) into
    build/wav; the host tests build it, so CI compiles it with -Werror.
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2026-10-06 Enclosure: layout of the real board, marked as a draft
    The model had six keys in a row with RST and BOOT elsewhere, the jacks
    on the left and USB at the back. The Audio Kit V2.2 (A618) has one row
    of eight keys in front (RST, BOOT, KEY1..KEY6, 8.5 mm apart), the jacks
    on the right, USB on the left (POWER in front, UART towards the SD
    slot), and the antenna end of the ESP32-A1S sticks out over the back
    edge. The model follows that: holes for a paper clip for RST and BOOT,
    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
    [bottom.stl, buttons.stl, horchposten_case.scad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]
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2026-10-06 Docs: how the signal chain and the auto pitch work
    docs/algorithms.md explains every stage with its formulas and numbers:
    clocks, DC block, the Butterworth band pass design, AGC with hang and
    look-ahead, the Hilbert pair and the analytic signal, the four stereo
    modes (binaural by pitch with its phase law and widths), the limiter,
    how each kind of change is faded without clicks or dropouts, the auto
    pitch with its noise reference and range rule, and what the host tests
    check. Linked from the README.
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2026-10-12 Enclosure printed and fitted: no longer a draft
